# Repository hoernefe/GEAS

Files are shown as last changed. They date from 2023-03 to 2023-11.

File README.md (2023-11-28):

# GEAS
**A mobile sensor platform for big scale collection of geodata.**
https://geasproject.wixsite.com/geodatenerfassungs/

The Geodata Acquisition and Analysis System aims to develop a mobile system that enables large-scale and efficient collection of geodata. The collected data should be presented in a clear and insightful way to draw conclusions for sustainable and health-oriented urban development optimization.

One successful application of this system was a data collection campaign on the topic of fine particle pollution in the Karlsruhe area. For this purpose, a sensor module based on a Raspberry Pi was mounted on bicycles to systematically capture data of the city area of Karlsruhe. The data collected by the sensor module were stored in a database and processed by a Python program. The results were visualized using GIS software.

The geodata acquisition and analysis system has multiple use cases and enables decision-making based on sound data for sustainable and health-oriented urban development.

## Sensor platform
In every sensor box has a Raspberry Pi is build in. On This Pi the Code from the folder labeld Pi is running. All used libraries have to be installed. For thosw which weren't already pip wasused for the installation. The font-files from the oled library had some problems, but we were able to fix these by putting our ode inside it's folder. To automatically start everything we added the following at the end of the bashrc file:
```
echo Running at boot
python /home/pi/lib_oled96/Upload_sql_oled_4.py> out.txt 2> err.txt &
python /home/pi/lib_oled96/auto_shutdown.py > out2.txt 2> err2.txt &
```

## Database
For the database we used a phpMyAdmin server, which is very similar to MySQL. Any SQL-based system should do the trick.

The structure we used is the following:
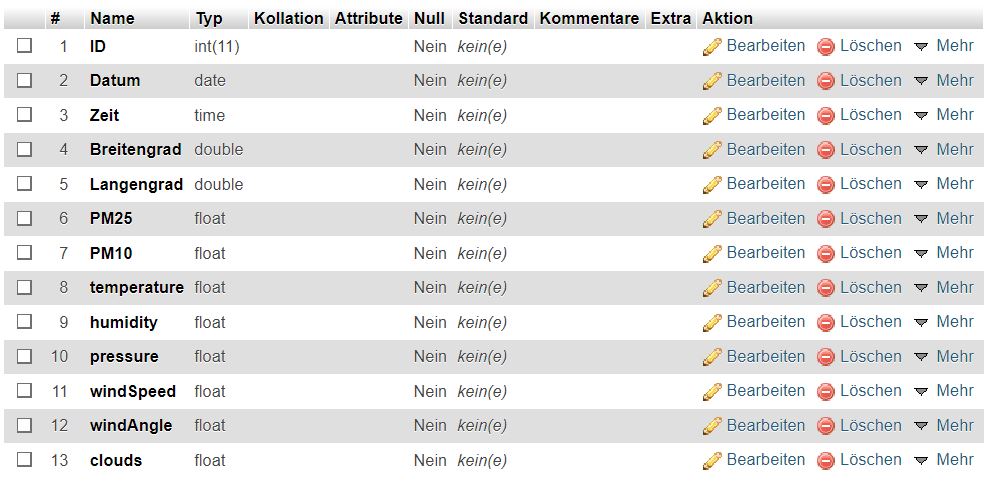
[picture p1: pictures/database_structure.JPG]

(Breitengrad is german for latitude and Langengrad means longitude)

## Analysis
The geodata from the database requires processing for a good visualization. To do this, we wrote some python code. It can be found in the analysis folder. For the python code all neccesary libraries must be imported. Alternatively our .exe file may be used, but your computer will give you a virus threat warning and you shouldn't trust people on the internet, so try to use the python file.
Currently the interface is in German, but we're working on an English version for easier use.

## Parts
1x Raspberry Pi Zero WH 

1x Raspberry Pi heatsink 

1x 16gb SD-Card 

1x SDS011 PM Sensor 

1x Neo6m GPS-Module 

1x GPS-Antenna 

1x Huawei E5576-320 SIM-Router 

1x SIM-Card  

1x Anker Powercore 1000mAh power bank 

1x 90-degree angled USB-A to Micro-USB cable 

1x 0,96in i2c OLED-Display 

1x Small plexiglass sheet 

1x On-Off Rocker switch 

1x NO Push-Button 

12x M3 Nylon Nuts + Bolts 

Wires for soldering 

Heat-Shrink tubing  

Double sided tape 

Hot glue 

1x Bike mount (https://www.amazon.de/Rixen-Kaul-KlickFix-Bottlefix-Flaschenhalter/dp/B07498GS82) 

## Instructions
Print casing, intermediate floor and sensor opening filter with 1,75mm PLA filament 

Mount filter on sensor opening (heat to attach) and place sensor into designated space 

Solder wires as shown on the soldering diagram. 

Cut and solder angled USB cable as shown on soldering diagram. 

Connect angled USB cable to power bank and place into designated spot, load SIM-card into SIM-Router and place into designated spot, cover with intermediate floor, feed the ends of soldered USB cable through the hole in the middle 

Screw Raspberry Pi Zero onto intermediate floor, connect the original Micro-USB end to power input 

Connect remaining Micro-USB end to the SIM-Router below 

Screw GPS-Module into place, connect to Raspberry Pi with the soldered cables, tape antenna onto back wall of the top part, cut a small hole into the side of the top for the antenna cable 

Connect Sensor to Raspberry Pi via the included adapter 

Glue plexiglass into designated hole in the top, glue OLED-display underneath, connect to Raspberry Pi with soldered cables 

Place rocker switch into hole next to “power” in the top, connect to Raspberry Pi with the soldered cables 

Place NO-Button into hole next to “eco” in the top, connect to the cut cable from step 4 

Load Program onto SD-Card, load into Raspberry Pi 

Close module by screwing top onto bottom 

Begin data collection by activating the rocker switch, end session by first pressing the “eco”-Button until the display reads “Ausschalten”, only then turn off the module via the rocker switch. 

## Wiring
The power distribution works as seen here:
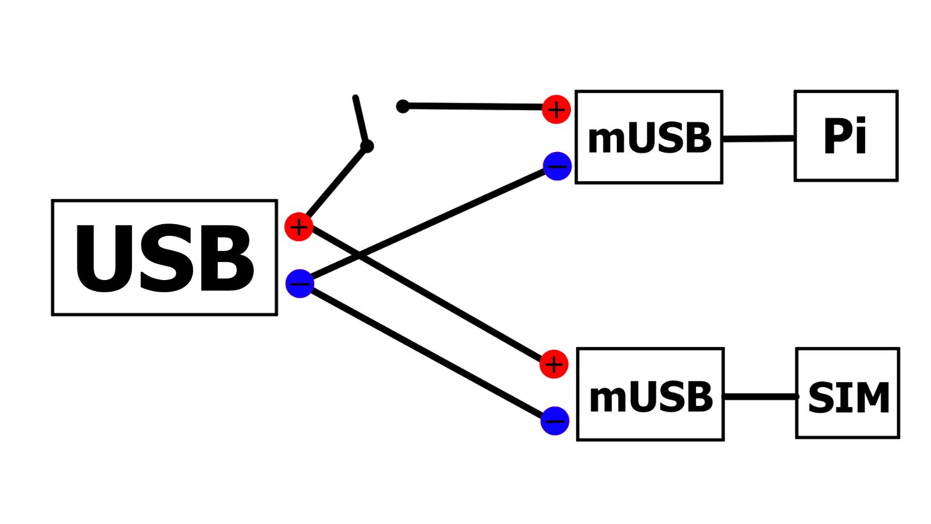
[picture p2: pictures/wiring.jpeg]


Soldering diagram:
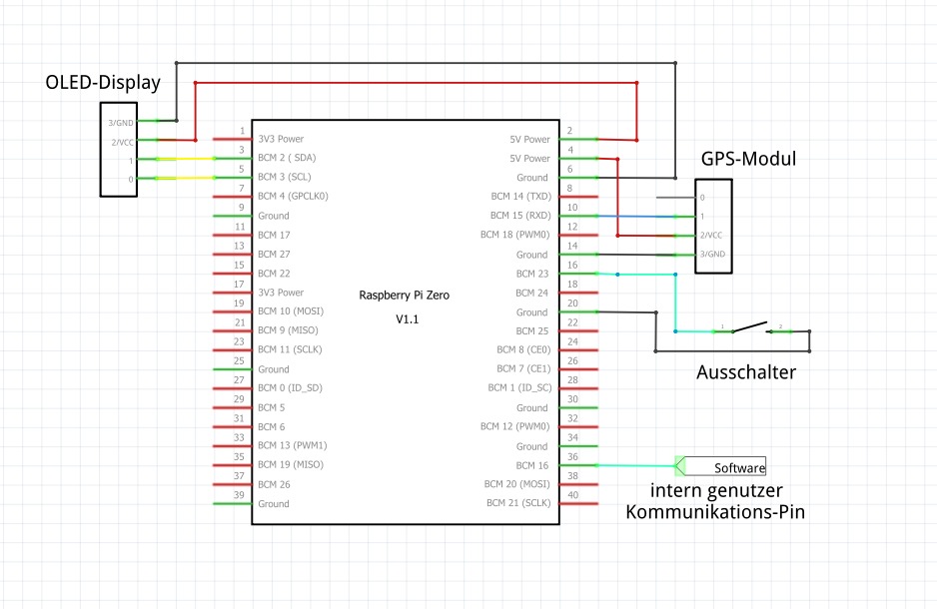
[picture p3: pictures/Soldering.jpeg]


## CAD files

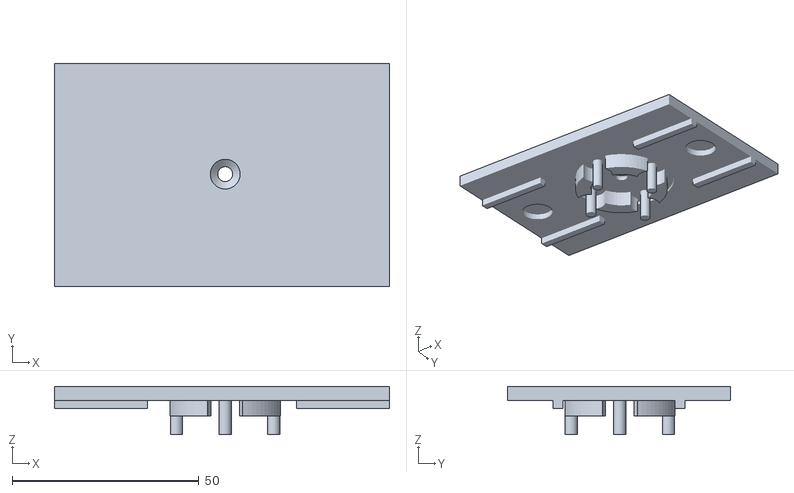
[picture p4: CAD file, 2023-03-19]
3d-files/bicycle mount.stl
89.8 x 59.8 x 12.9

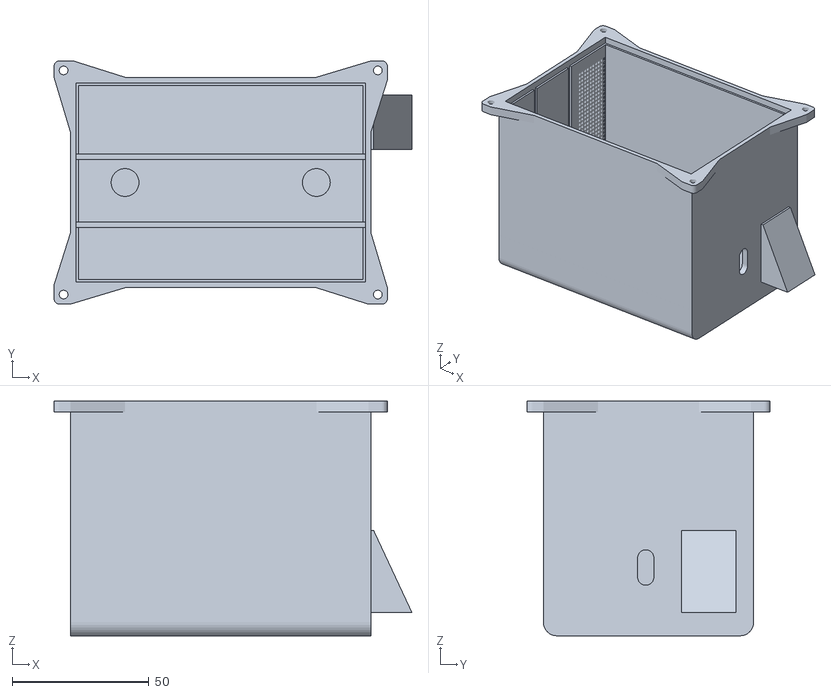
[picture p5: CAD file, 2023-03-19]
3d-files/bottom.stl
131.0 x 89.0 x 85.9

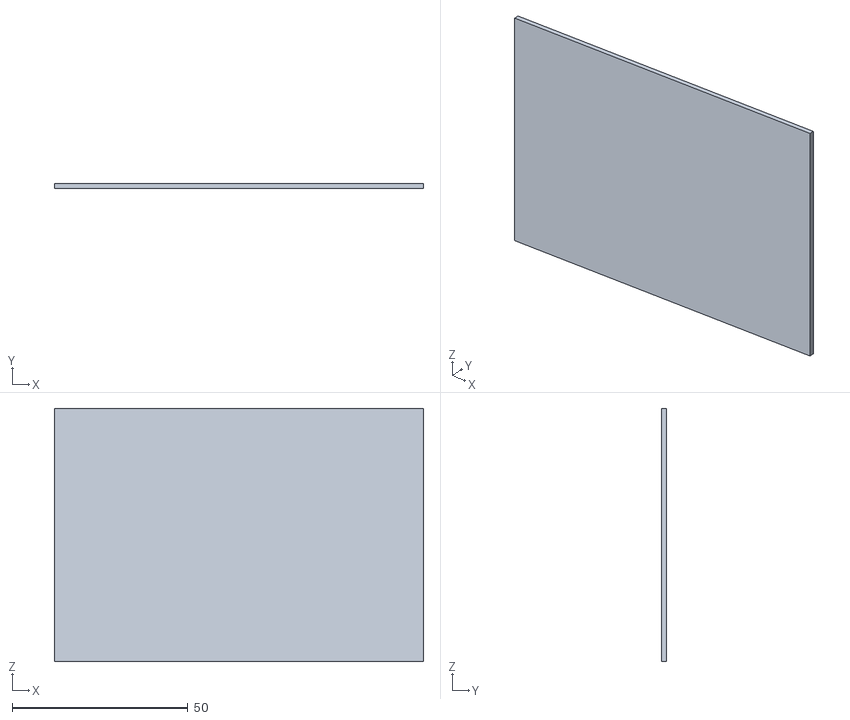
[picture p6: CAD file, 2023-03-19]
3d-files/seperating walls.stl
105.0 x 1.50 x 72.0

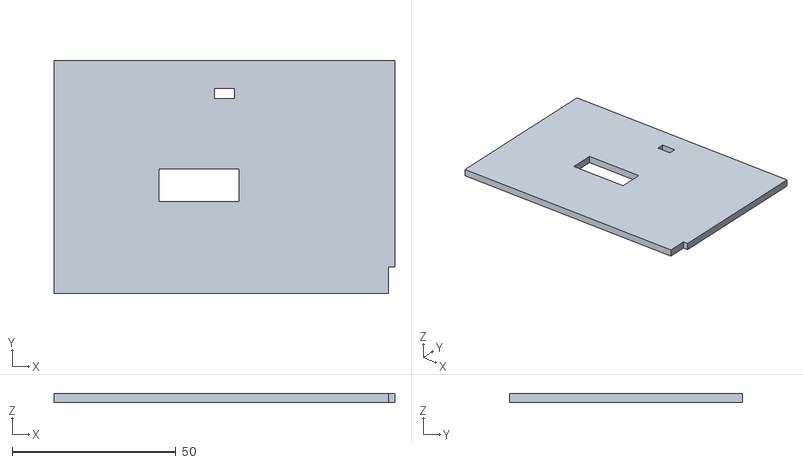
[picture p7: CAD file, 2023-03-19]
3d-files/intermediate floor.stl
104.0 x 71.0 x 2.80

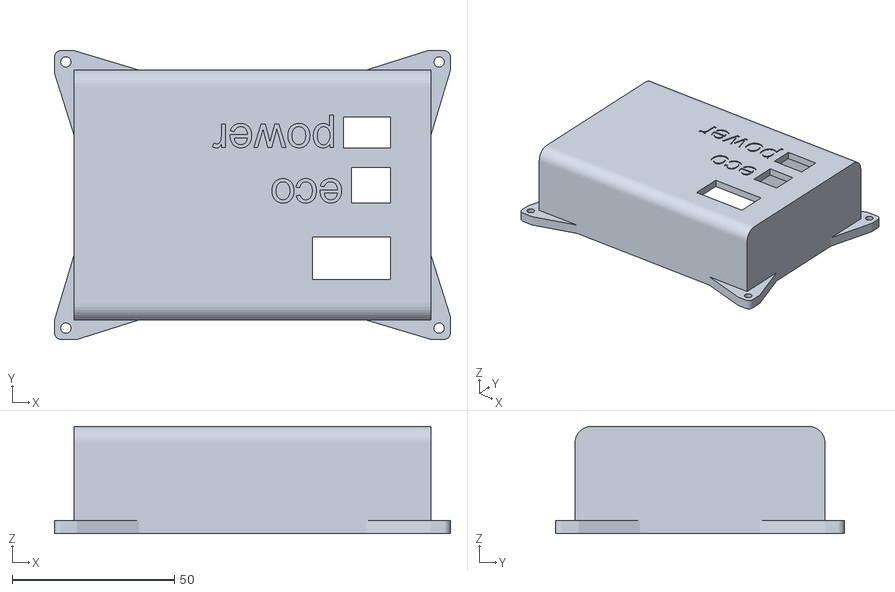
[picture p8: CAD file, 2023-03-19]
3d-files/top.stl
122.0 x 89.0 x 33.0

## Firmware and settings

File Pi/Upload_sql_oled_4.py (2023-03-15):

from __future__ import print_function
from datetime import *
import RPi.GPIO as GPIO
import serial, struct, sys, time, subprocess, time, string, pynmea2, socket, os
import urllib
import mysql
import mysql.connector

from lib_oled96 import ssd1306
from smbus import SMBus
from PIL import ImageFont

datenDesWetters = [0,0,0,0,0,0]

print("Upload_sql_oled_4.py wurde gestartet (das ist eine nachrich, die ich ins Proragramm geschriben habe)")

i2cbus = SMBus(1)
oled = ssd1306(i2cbus)
draw = oled.canvas
FreeSans12 = ImageFont.truetype('FreeSans.ttf', 12)
FreeSans16 = ImageFont.truetype('FreeSans.ttf', 16)
FreeSans20 = ImageFont.truetype('FreeSans.ttf', 20)


GPIO.setmode(GPIO.BCM)

GPIO.setup(16, GPIO.IN, pull_up_down=GPIO.PUD_DOWN)


oled.cls()
oled.display()
draw.text((0, 0), "Wilkommen", font=FreeSans20, fill=1)
draw.text((0, 30), "Bitte warten bis Werte" , font=FreeSans12, fill=1)
draw.text((0, 45), "erscheinen" , font=FreeSans12, fill=1)
oled.display()

time.sleep(5)

status = "Not connected"

while status != "Connected":
        try:
                url = "https://www.google.com"
                urllib.urlopen(url)
                status = "Connected"
        except:
                status = "Not connected"
        oled.cls()
        oled.display()
        draw.text((0, 0), "Verbindungsfehler", font=FreeSans16, fill=1)
        draw.text((0, 30), "Keine Verbindung zum" , font=FreeSans12, fill=1)
        draw.text((0, 45), "Internet vorhanden" , font=FreeSans12, fill=1)
        oled.display()
        print(status)
        time.sleep(2)

oled.cls()
oled.display()
draw.text((0, 0), "Verbunden", font=FreeSans16, fill=1)
draw.text((0, 30), "Verbindung zum" , font=FreeSans12, fill=1)
draw.text((0, 45), "Internet vorhanden" , font=FreeSans12, fill=1)
oled.display()

time.sleep(2)

#enter your data for the server
mydb = mysql.connector.connect(
  host="enter host",
  user="enter user",
  password="enter password",
  database="enter database"
)

mycursor = mydb.cursor()

now = datetime.now()

anzahl=0

gezeigt=False

f=open('daten.csv', 'a')


DEBUG = 0
CMD_QUERY_DATA = 4

ser = serial.Serial()
ser.port = "/dev/ttyUSB0"
ser.baudrate = 9600

ser.open()
ser.flushInput()

def construct_command(cmd, data=[]):
    assert len(data) <= 12
    data += [0,]*(12-len(data))
    checksum = (sum(data)+cmd-2)%256
    ret = "\xaa\xb4" + chr(cmd)
    ret += ''.join(chr(x) for x in data)
    ret += "\xff\xff" + chr(checksum) + "\xab"

    if DEBUG:
        dump(ret, '> ')
    return ret

def process_data(d):
    r = struct.unpack('<HHxxBB', d[2:])
    pm25 = r[0]/10.0
    pm10 = r[1]/10.0
    checksum = sum(ord(v) for v in d[2:8])%256
    return [pm25, pm10]

def read_response():
    byte = 0
    while byte != "\xaa":
        byte = ser.read(size=1)

    d = ser.read(size=9)

    if DEBUG:
        dump(d, '< ')
    return byte + d

def cmd_query_data():
    ser.write(construct_command(CMD_QUERY_DATA))
    d = read_response()
    values = []
    if d[1] == "\xc0":
        values = process_data(d)
    return values


#getting the weatherdata from openweathermap
def wetterdaten():
    import urllib
    import time

    status = "Not connected"

    while status != "Connected":
        try:
            urllib.urlopen("https://www.google.com")
            status = "Connected"
        except:
            status = "Not connected"
        #print(status)
        time.sleep(2)

    wetterdaten = [0,0,0,0,0,0]

    response=urllib.urlopen("http://api.openweathermap.org/data/2.5/weather?appid=[enter APPID]&q=Karlsruhe") #the brackets have to be replaced with your own ID

    x = response.read()

    #print('Empfangene Daten')
    #print x

    #print('-------------------')
    #print('Temperatur in Grad Celsius')

    temp_string = x.split("temp",1)[1]
    cut_temp_string = temp_string.split(",",1)[1]
    temp_string =temp_string.replace(cut_temp_string, "")
    temp_string = temp_string[2:]
    cut_temp_string = temp_string[-1:]
    temp_string = temp_string.replace(cut_temp_string, "")
    temp = float(temp_string)
    temp = temp - 273.15
    #print temp
    wetterdaten [0] = temp

    #print('-------------------')
    #print('Feuchtigkeit in Prozent')
    humi_string = x.split("humidity",1)[1]
    cut_humi_string = humi_string.split(",",1)[1]
    humi_string = humi_string.replace(cut_humi_string, "")
    humi_string = humi_string[2:]
    cut_humi_string = humi_string[-1:]
    humi_string = humi_string.replace(cut_humi_string, "")
    cut_humi_string = humi_string[-1:]
    if cut_humi_string == "}":
        #print "extra"
        humi_string = humi_string.replace(cut_humi_string, "")
    humi = float(humi_string)
    #print humi
    wetterdaten [1] = humi

    #print('-----------------')
    #print('Luftdruck in hPa')

    pres_string = x.split("pressure",1)[1]
    cut_pres_string = pres_string.split(",",1)[1]
    pres_string = pres_string.replace(cut_pres_string, "")
    pres_string = pres_string[2:]
    cut_pres_string = pres_string[-1:]
    pres_string = pres_string.replace(cut_pres_string, "")
    pres = float(pres_string)
    #print pres
    wetterdaten [2] = pres

    #print('----------------')
    #print('Windgeschwindigkeit in m/s')

    sped_string = x.split("speed",1)[1]
    cut_sped_string = sped_string.split(",",1)[1]
    sped_string = sped_string.replace(cut_sped_string, "")
    sped_string = sped_string[2:]
    cut_sped_string = sped_string[-1:]
    sped_string = sped_string.replace(cut_sped_string, "")
    sped = float(sped_string)
    #print sped
    wetterdaten [3] = sped

    #print('---------------')
    #print('Windrichtung in Grad')

    deg_string = x.split("deg",1)[1]
    cut_deg_string = deg_string.split(",",1)[1]
    deg_string = deg_string.replace(cut_deg_string, "")
    deg_string = deg_string[2:]
    cut_deg_string = deg_string[-1:]
    deg_string = deg_string.replace(cut_deg_string, "")
    deg = float(deg_string)
    #print deg
    wetterdaten [4] = deg

    #print('-------------------')
    #print('Wolken in Prozent')
    clou_string = x.split("all",1)[1]
    cut_clou_string = clou_string.split(",",1)[1]
    clou_string = clou_string.replace(cut_clou_string, "")
    clou_string = clou_string[2:]
    cut_clou_string = clou_string[-1:]
    clou_string = clou_string.replace(cut_clou_string, "")
    cut_clou_string = clou_string[-1:]
    if cut_clou_string == "}":
        #print "extra"
        clou_string = clou_string.replace(cut_clou_string, "")
    clou = float(clou_string)
    #print clou
    wetterdaten [5] = clou

    #print('-------------------')
    #print('Liste')
    #print wetterdaten
    return wetterdaten

datenDesWetters = wetterdaten()

print(datenDesWetters)

anzahl = 0

t0 = time.time()


#when all data is available it is sen to the server and a massage is displayed on the oled
while True:

    t1 = time.time()
    if t1-t0 > 900:
        datenDesWetters = wetterdaten()
        t0 = time.time()

    if GPIO.input(16):
        print("gestoppt")
        f.close()
        oled.cls()
        oled.display()
        oled.display()
        draw.text((0, 0), "Ausgeschaltet", font=FreeSans20, fill=1)
        draw.text((0, 30), "Die Box schaltet sich" , font=FreeSans12, fill=1)
        draw.text((0, 45), "jetzt aus" , font=FreeSans12, fill=1)
        oled.display()
        while True:
            time.sleep(1)

    print("loop")
    now = datetime.now()
    port="/dev/ttyAMA0"
    serG=serial.Serial(port, baudrate=9600, timeout=0.5)
    dataout = pynmea2.NMEAStreamReader()
    newdata=serG.readline()
    values = cmd_query_data();
    if newdata[0:6] == "$GPRMC":
        newmsg=pynmea2.parse(newdata)
        lat=newmsg.latitude
        lng=newmsg.longitude

        if(lat + lng != 0):

            #gezeigt=False

            gps = "Latitude :" + str(lat) + ",  Longitude: " + str(lng)
            print(gps)
            print(now.strftime("%d/%m/%Y"), now.strftime("%H:%M:%S"), ", PM2.5: ", values[0], ", PM10: ", values[1])

            sql = "INSERT INTO FeinstaubVonPi (ID, Datum, Zeit, Breitengrad, Langengrad, PM25, PM10, temperature, humidity, pressure, windSpeed, windAngle, clouds) VALUES (" '1' + ',' + now.strftime("%Y%m%d") + ',' + now.strftime("%H%M%S") + ','+ str(lat) + ',' + str(ln$            mycursor.execute(sql)
            mydb.commit()

            print(mycursor.rowcount, "record inserted.")

            print(now.strftime("%Y/%m/%d"), now.strftime("%H:%M:%S"), ',',str(lat), ',', str(lng), ',', values[0], ',', values[1], file=f)
            anzahl = anzahl+1

            oled.cls()
            oled.display()

            draw.text((0, 0), "PM 2,5: ", font=FreeSans16, fill=1)
            draw.text((70, 0), str(values[0]), font=FreeSans16, fill=1)

            draw.text((0, 15), "PM 10: ", font=FreeSans16, fill=1)
            draw.text((70, 15), str(values[1]), font=FreeSans16, fill=1)

            draw.text((0, 30), str(lat), font=FreeSans16, fill=1)
            draw.text((0, 45), str(lng), font=FreeSans16, fill=1)


            oled.display()

        else:

            #if(not gezeigt):

            oled.cls()
            oled.display()
            gezeigt=True

            draw.text((0, 0), "Verbindungsfehler", font=FreeSans16, fill=1)
            draw.text((0, 30), "Es werden keine GPS" , font=FreeSans12, fill=1)
            draw.text((0, 45), "Daten empfangen" , font=FreeSans12, fill=1)

            oled.display()
            time.sleep(1 )

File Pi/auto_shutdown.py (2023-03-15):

import RPi.GPIO as GPIO
import time
import os

from lib_oled96 import ssd1306
from smbus import SMBus
from PIL import ImageFont

i2cbus = SMBus(1)
oled = ssd1306(i2cbus)
draw = oled.canvas
FreeSans12 = ImageFont.truetype('FreeSans.ttf', 12)
FreeSans16 = ImageFont.truetype('FreeSans.ttf', 16)
FreeSans20 = ImageFont.truetype('FreeSans.ttf', 20)

time.sleep(2)

GPIO.setmode(GPIO.BCM)

GPIO.setup(23, GPIO.IN, pull_up_down=GPIO.PUD_UP)
GPIO.setup(16, GPIO.OUT)

GPIO.output(16, False)

#The GPIO pinis used to communicate between the two programms. We know this is ugly and multithreading would have made it way easier, but it works for V1. V2 will be better

print("LOW")

while True:
     button_state = GPIO.input(23)
     if button_state == False:
        oled.cls()
        oled.display()
        draw.text((0, 0), "Ausgeschaltet", font=FreeSans20, fill=1)
        draw.text((0, 30), "Die Box schaltet sich" , font=FreeSans12, fill=1)
        draw.text((0, 45), "jetzt aus" , font=FreeSans12, fill=1)
        oled.display()
        print("HIGH")
        GPIO.output(16, True)
        time.sleep(2)
        oled.cls()
        oled.display()
        os.system('poweroff')
        while True:
            print("fertig")
            time.sleep(100)
